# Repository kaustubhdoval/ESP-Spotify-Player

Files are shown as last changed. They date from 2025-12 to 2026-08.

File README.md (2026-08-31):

  <h1 align="center">ESP Spotify Player</h1>

  <p align="center">
    A Physical Spotify Remote, built around a custom ESP32-C3 PCB.
    <br />
    ·
    <a href="https://github.com/kaustubhdoval/ESP-Spotify-Player/issues">Report Bug</a>
    ·
    <a href="https://github.com/kaustubhdoval/ESP-Spotify-Player/issues">Request Feature</a>
    ·
  </p>

A Hardware Spotify Controller: buttons for play/pause/skip, a 128x64 OLED showing the current track and playback progress, and an on-device HTTPS server that handles the Spotify OAuth flow.

Ships as a from-scratch **KiCad PCB** (ESP32-C3) and also builds for a plain **ESP32 devkit** if you don't want to fab a board.

<p align="center">
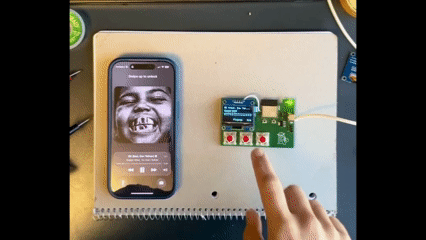
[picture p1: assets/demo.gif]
Demo of the Spotify player controlling playback
  
</p>
<p align="center">
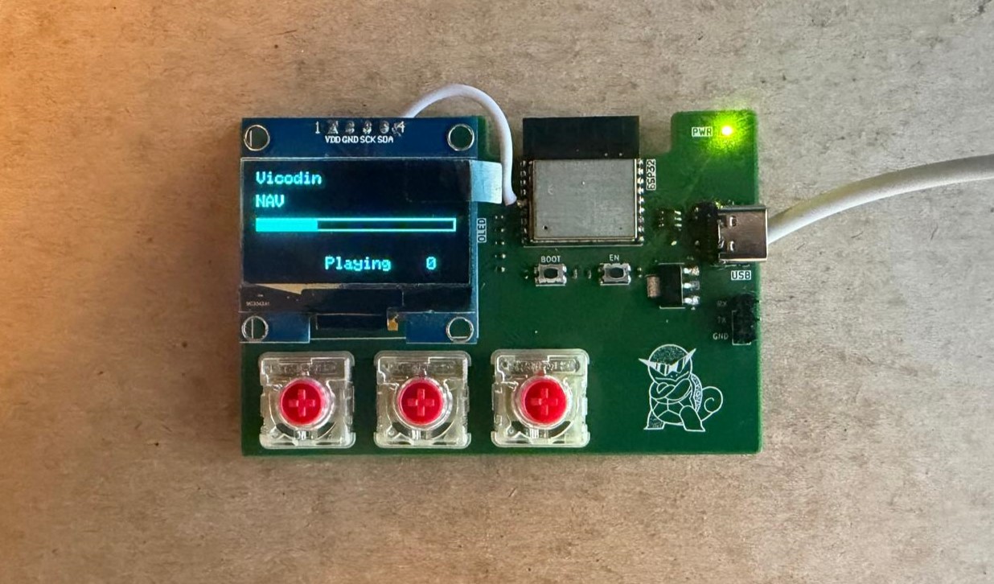
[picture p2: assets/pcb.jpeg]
Assembled custom PCB
  
</p>
<p align="center">
    Thanks to <a href="https://www.pcbway.com">PCBWay</a> for sponsoring fabrication!
  </p>

<br/>

## Features

- Play/pause, skip forward, skip back - instant, optimistic UI (screen updates before the Spotify API confirms)
- Live track name, artist, and playback-progress bar on a 128x64 SH1106 OLED
- Self-hosted OAuth: the ESP32 serves the Spotify login/callback pages itself over HTTPS, no server or app required
- Runs on a custom four-layer PCB (KiCad, ESP32-C3) **or** an off-the-shelf ESP32 devkit - see [Hardware](#hardware)

<br/>

## Repo Layout

```
src/    firmware (PlatformIO / Arduino framework)
pcb/    KiCad hardware design - schematic, PCB layout, fab/assembly outputs
lib/    vendored third-party library (patched for ESP32-C3 portability)
```

<br/>

## Hardware

This project supports two build targets. Pick whichever matches what you have.

| | Custom PCB | Generic ESP32 Devkit |
| --- | --- | --- |
| Board | ESP32-C3 (this repo's PCB) | Any classic ESP32 devkit |
| Rotary encoder (volume) | Not populated | Supported |
| PlatformIO environment  | `pcb` | `devkit` |
| Where to get it | Fab the board - see [View the PCB](#view-the-pcb) | Any ESP32 dev board you already own |

#### Wiring - Custom PCB (`env:pcb`)

| Component | Pin |
| --- | ----- |
| OLED SDA | GPIO6 |
| OLED SCL | GPIO7 |
| Previous button | GPIO5 |
| Play/Pause button | GPIO4 |
| Next button | GPIO3 |

No rotary encoder on this board - GPIO2 is a strapping pin on ESP32-C3, so it was dropped from the design.

#### Wiring - Generic Devkit (`env:devkit`)

| Component | Pin |
| --- | --- |
| OLED SDA | GPIO21 |
| OLED SCL | GPIO22 |
| Previous button | GPIO5  |
| Play/Pause button | GPIO18 |
| Next button | GPIO19 |
| Encoder CLK | GPIO4  |
| Encoder DT | GPIO2  |
| Encoder SW | GPIO15 |

> These pins are the environment defaults in `platformio.ini` - if your devkit's I2C or GPIOs are already used for something else, override them with `build_flags` in your environment rather than editing the source.

### View the PCB

The board is designed in KiCad. You can browse it interactively, no install required:

#### [**Open in KiCanvas »**](https://kicanvas.org/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)

Or open the files directly: [schematic](pcb/spotifyPlayerPcb.kicad_sch) · [PCB layout](pcb/spotifyPlayerPcb.kicad_pcb) · [assembly drawing](pcb/plots/spotifyPlayerPcb__Assembly.pdf) · [fab output](pcb/output/spotifyPlayerPcb.zip)

<br/>

## Setup

You need an **application registered on the Spotify Developer Dashboard** with the Web API enabled.

1. Rename [`src/secrets_EXAMPLE.h`](src/secrets_EXAMPLE.h) to `src/secrets.h`.
2. Fill in your WiFi credentials and Spotify `CLIENT_ID` / `CLIENT_SECRET` in `secrets.h`.
3. Build and flash for your hardware:

   ```sh
   pio run -e pcb -t upload      # custom PCB (ESP32-C3)
   # or
   pio run -e devkit -t upload   # generic ESP32 devkit
   ```

   > Custom PCB only: the board has no auto-reset circuit, just bare BOOT/RESET buttons. Hold **BOOT**, tap **RESET**, then release **BOOT** right as `pio run -t upload` starts trying to connect, or it'll fail with "Failed to connect to ESP32".

   If PlatformIO still can't find/upload to your board, flash the built binaries with `esptool` directly instead. Just build first (`pio run -e pcb`), then:

   ```sh
   esptool --chip esp32c3 --port COM3 write-flash ^
     0x0     .pio\build\pcb\bootloader.bin ^
     0x8000  .pio\build\pcb\partitions.bin ^
     0x10000 .pio\build\pcb\firmware.bin
   ```

   For a `devkit` build, swap `--chip esp32c3` for `--chip esp32` and `.pio\build\pcb\` for `.pio\build\devkit\`. Adjust `COM3` to your board's port. (This is the newer standalone `esptool` v5+ syntax; PlatformIO's bundled `esptool.py` uses `write_flash` with an underscore instead.)

4. Check the ESP's IP address on the OLED, or via the serial monitor:

   ```sh
   pio device monitor -e pcb      # or -e devkit
   ```

5. Add `https://<ESP_IP>/callback` as a Redirect URI on your Spotify app dashboard, and set the same value as `REDIRECT_URI` in `secrets.h`.
6. Re-flash with the updated `secrets.h`, then navigate to `https://<ESP_IP>` and log in with Spotify.

That's it - the device handles the OAuth exchange itself and starts controlling playback.

<br/>

## Dependencies

- adafruit/Adafruit GFX Library@^1.12.0
- adafruit/Adafruit SH110X@^2.1.12
- bblanchon/ArduinoJson@^7.4.1
- arduinogetstarted/ezButton@^1.0.6

Vendored locally in [lib/esp32_https_server](lib/esp32_https_server) (not pulled from the registry):

- fhessel/esp32_https_server@^1.0.0, patched to use `mbedtls_sha1` instead of the classic-ESP32-only `hwcrypto/sha.h`, so it builds on ESP32-C3 too.

<br/>

## Credits

- Thanks again to <a href="https://www.pcbway.com" target="_b;ank">PCBWay</a> for sponsoring fabrication.
  Their PCB manufacturing quality and service made it easy to bring the design from the schematic and layout to a finished, assembled board.
  <br/>
- Inspired by [MakeItForLess's Spotify Player](https://gitlab.com/makeitforless/spotify_controller)

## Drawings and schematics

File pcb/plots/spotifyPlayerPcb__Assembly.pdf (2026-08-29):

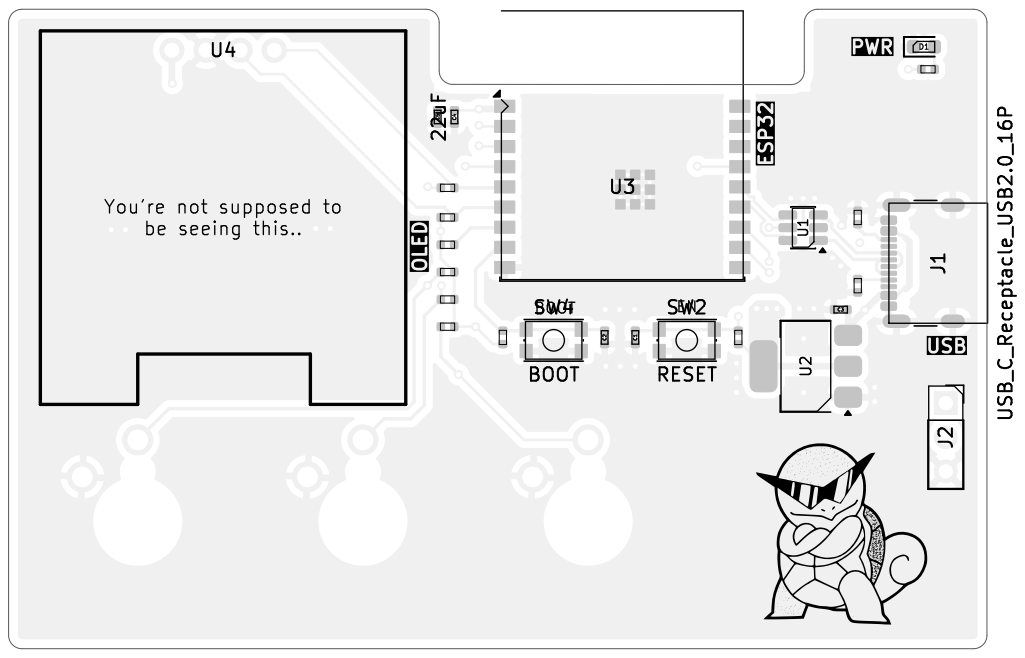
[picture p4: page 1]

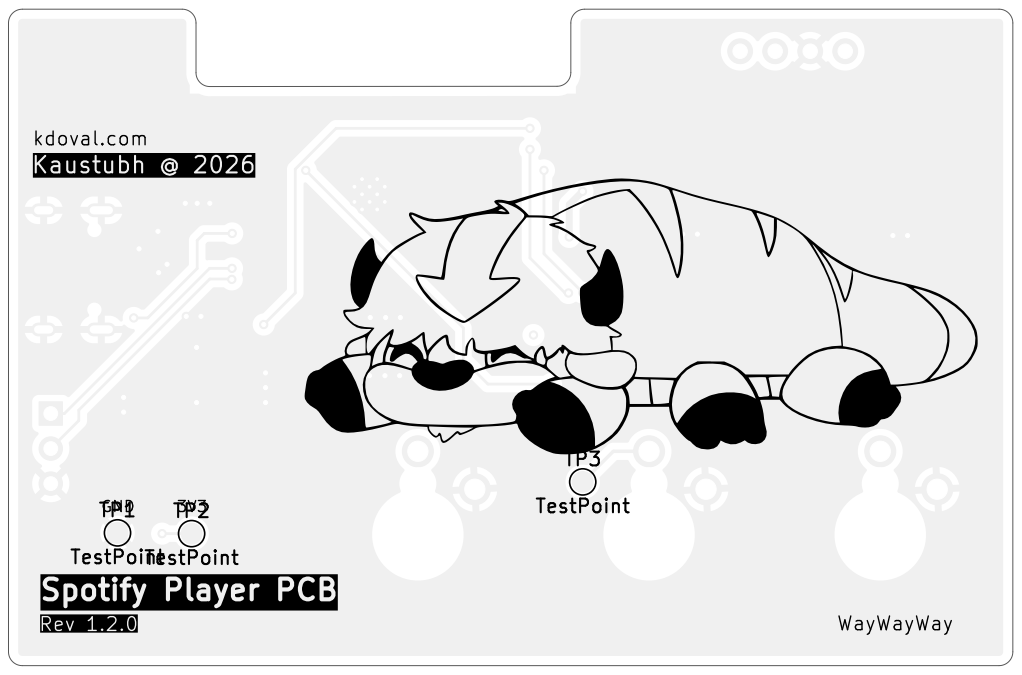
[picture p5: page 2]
GND; WayWayWay; kdoval.com; D Date: KiCad; E.D.A. 9.0.6 Size: A4; Rev:; Id: /1 Title: File: spotifyPlayerPcb.kicad_pcb Sheet: Black; And; White; BOT Board2Pdf:; Black; BOT -; Page 2/2

TestPoint TP3 TestPoint TP2 TestPoint TP1

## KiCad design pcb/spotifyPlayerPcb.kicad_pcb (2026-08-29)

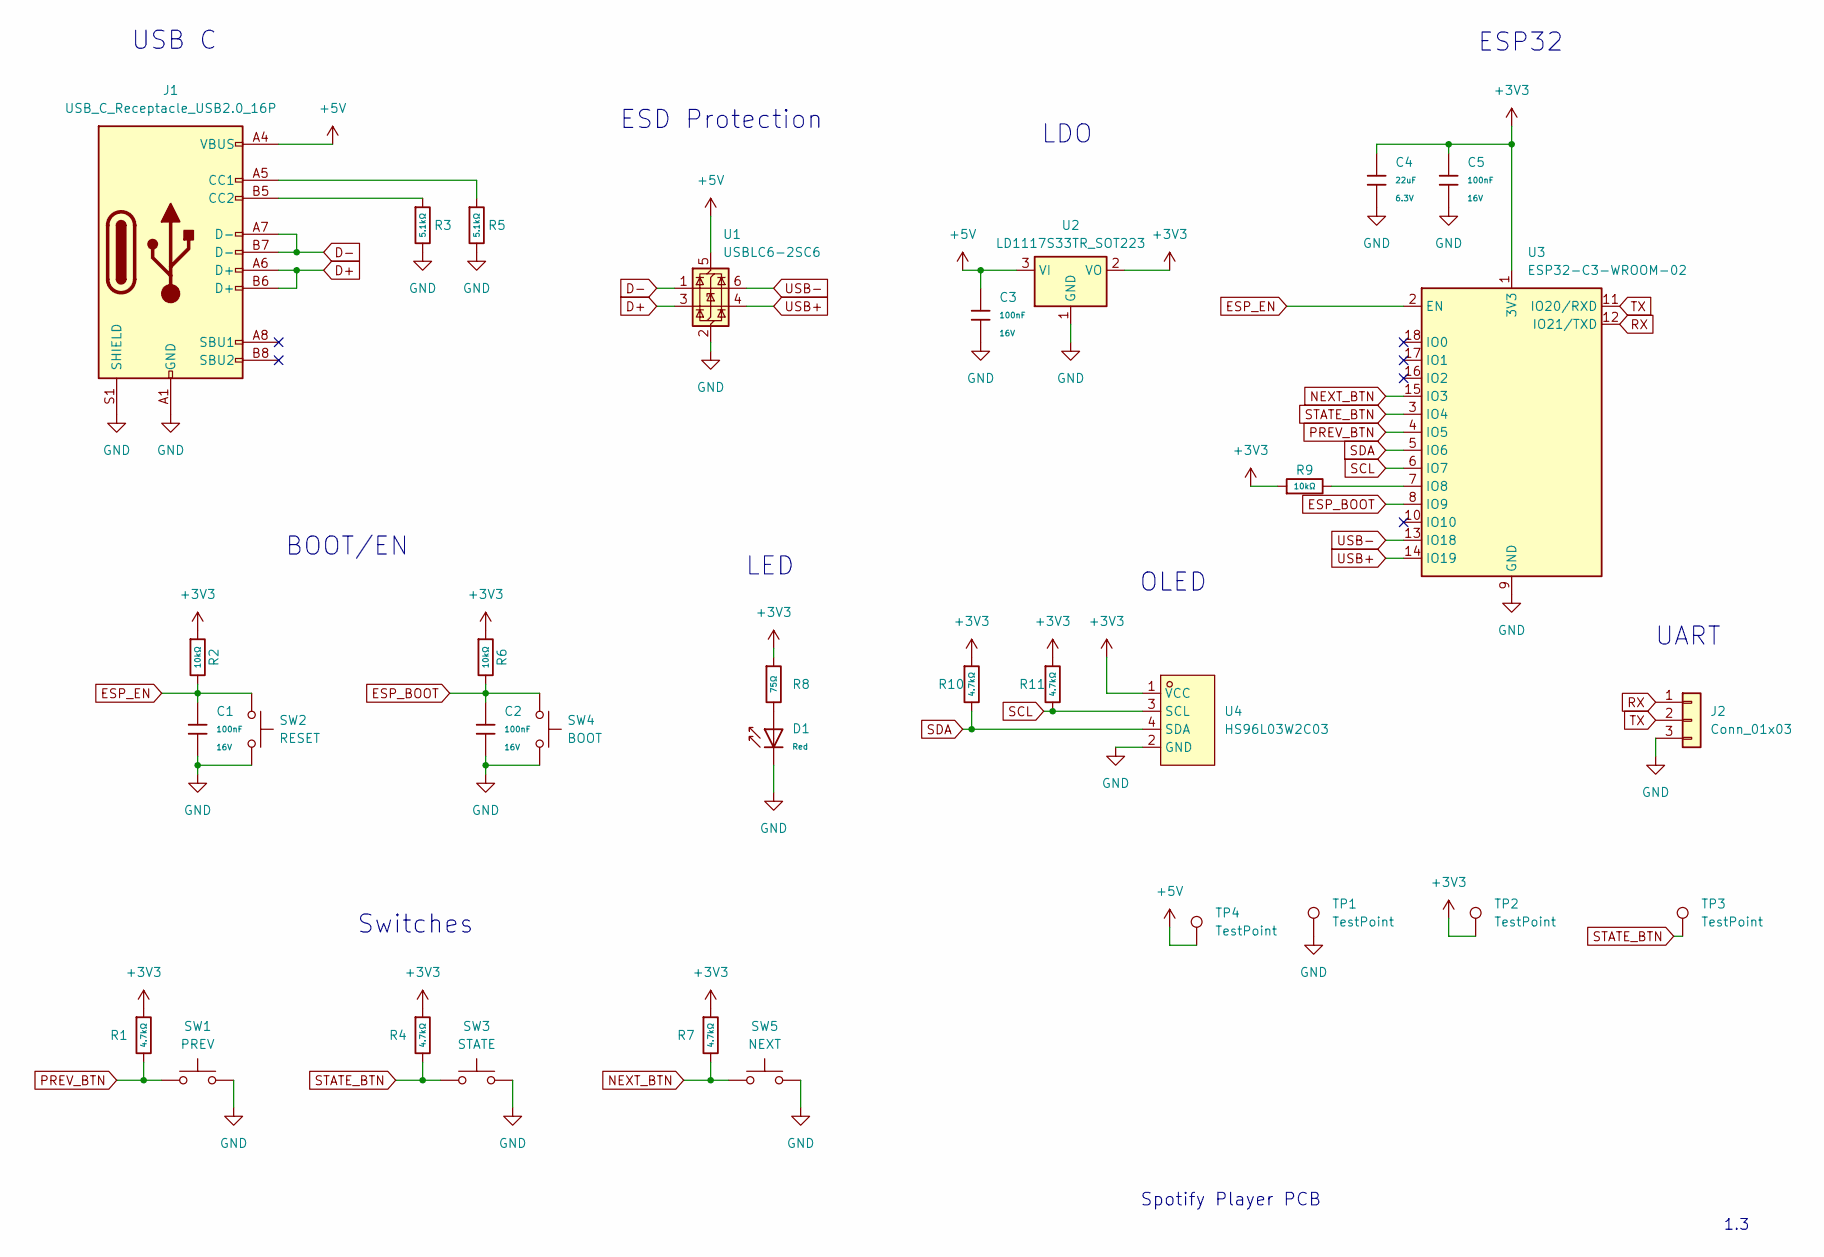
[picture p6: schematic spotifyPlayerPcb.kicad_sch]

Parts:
C1, C2, C3, C5: 100nF; C_0402; Voltage Rated 16V; Tolerance ±10%; Part CL05B104KO5NNNC; LCSC C1525
C4: 22uF; C_0402; Voltage Rated 6.3V; Tolerance ±20%; Part CL10A226MQ8NRNC; LCSC C59461
D1: Red; D_0603; Part KT-0603R; LCSC C2286
J1: USB_C_Receptacle_USB2.0_16P; USB_C_Receptacle_GCT_USB4105-xx-A_16P_TopMnt_Horizontal
J2: Conn_01x03; PinSocket_1x03_P2.54mm_Vertical
R1, R4, R7, R10, R11: 4.7kΩ; R_0402; Overload Voltage (Max) 50V; Tolerance ±1%; Part 0402WGF4701TCE; LCSC C25900
R2, R6, R9: 10kΩ; R_0402; Overload Voltage (Max) 50V; Tolerance ±1%; Part 0402WGF1002TCE; LCSC C25744
R3, R5: 5.1kΩ; R_0402; Overload Voltage (Max) 50V; Tolerance ±1%; Part 0402WGF5101TCE; LCSC C25905
R8: 75Ω; R_0402; Overload Voltage (Max) 50V; Tolerance ±1%; Part 0402WGF750JTCE; LCSC C25133
SW1: PREV; Cherry-MX-Low-Profile
SW2: RESET; SW_Push_1P1T_NO_CK_KMR2
SW3: STATE; Cherry-MX-Low-Profile
SW4: BOOT; SW_Push_1P1T_NO_CK_KMR2
SW5: NEXT; Cherry-MX-Low-Profile
TP1, TP2, TP3, TP4: TestPoint; TestPoint_Pad_D1.5mm
U1: USBLC6-2SC6; SOT-23-6
U2: LD1117S33TR_SOT223; SOT-223-3_TabPin2
U3: ESP32-C3-WROOM-02
U4: HS96L03W2C03; OLED-TH_L27.8-W27.2-P2.54_C9900033791; LCSC Part C5248080

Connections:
+3V3: C4.1, C5.1, R1.1, R2.1, R4.1, R6.1, R7.1, R8.1, R9.1, R10.1, R11.1, TP2.1, U2.2 (VO), U3.1 (3V3), U4.1 (VCC)
+5V: C3.1, J1.A4 (VBUS), J1.A9 (VBUS), J1.B4 (VBUS), J1.B9 (VBUS), TP4.1, U1.5 (VBUS), U2.3 (VI)
D+: J1.A6 (D+), J1.B6 (D+), U1.3 (I/O2)
D-: J1.A7 (D-), J1.B7 (D-), U1.1 (I/O1)
ESP_BOOT: C2.1, R6.2, SW4.1, U3.8 (IO9)
ESP_EN: C1.1, R2.2, SW2.1, U3.2 (EN)
GND: C1.2, C2.2, C3.2, C4.2, C5.2, D1.1, J1.A1 (GND), J1.A12 (GND), J1.B1 (GND), J1.B12 (GND), J1.S1 (SHIELD), J2.3, R3.2, R5.2, SW1.2, SW2.2, SW3.2, SW4.2, SW5.2, TP1.1, U1.2 (GND), U2.1 (GND), U3.9 (GND), U3.19 (GND), U4.2 (GND)
NEXT_BTN: R7.2, SW5.1, U3.15 (IO3)
unnamed: D1.2, R8.2
unnamed: J1.A5 (CC1), R5.1
unnamed: J1.B5 (CC2), R3.1
unnamed: R9.2, U3.7 (IO8)
PREV_BTN: R1.2, SW1.1, U3.4 (IO5)
RX: J2.1, U3.12 (IO21/TXD)
SCL: R11.2, U3.6 (IO7), U4.3 (SCL)
SDA: R10.2, U3.5 (IO6), U4.4 (SDA)
STATE_BTN: R4.2, SW3.1, TP3.1, U3.3 (IO4)
TX: J2.2, U3.11 (IO20/RXD)
USB+: U1.4 (I/O2), U3.14 (IO19)
USB-: U1.6 (I/O1), U3.13 (IO18)

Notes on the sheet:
Spotify Player PCB
UART
Switches
LED
LDO
BOOT/EN
ESD Protection
USB C
ESP32
OLED
1.3

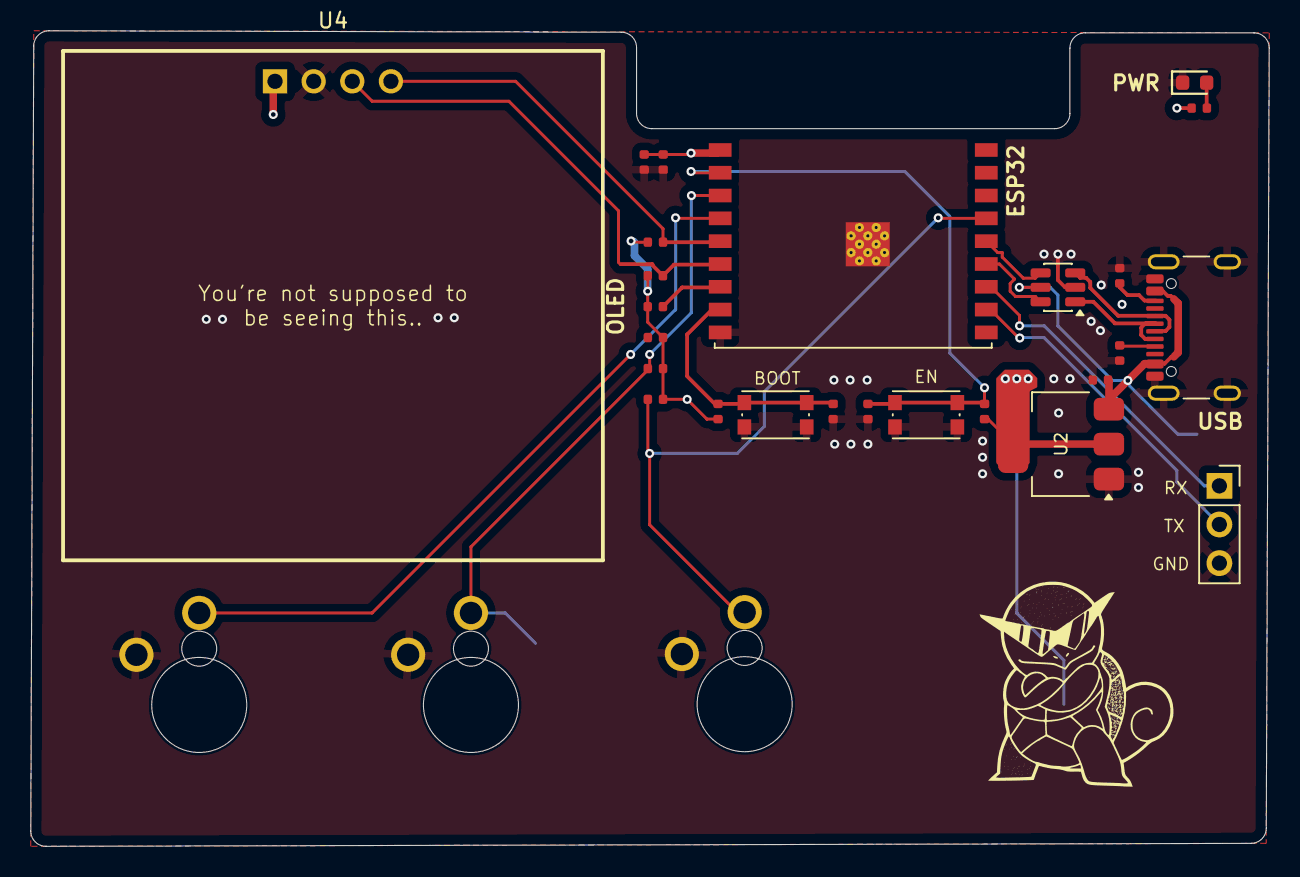
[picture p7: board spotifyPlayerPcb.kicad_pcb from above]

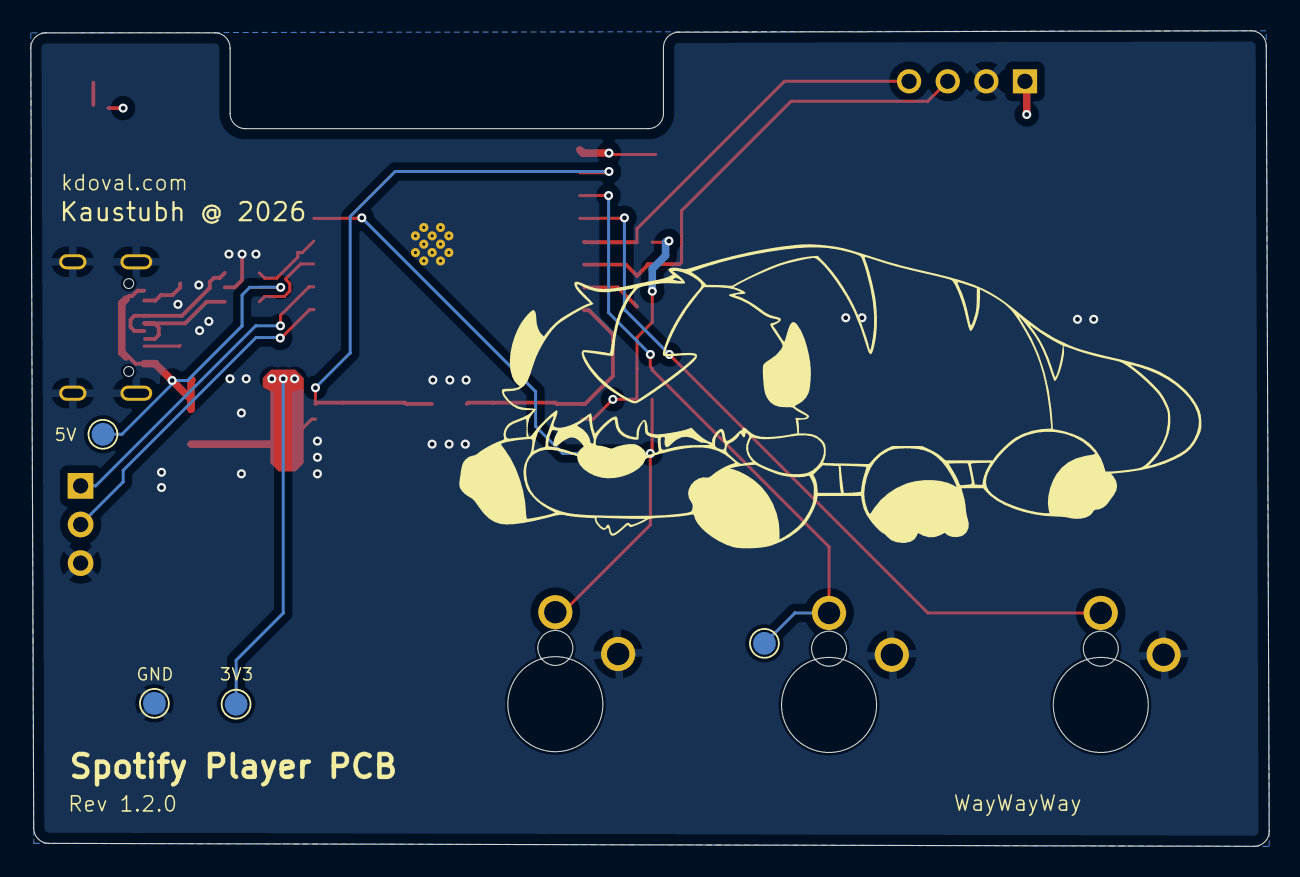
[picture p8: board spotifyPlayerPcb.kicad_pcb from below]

Board: 4 copper layers, 81.4 x 53.6 mm, 32 parts (4 on the bottom side), 20 nets.

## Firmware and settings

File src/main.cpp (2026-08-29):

/*ESP Spotify Player
- By Kaustubh
*/
#include <Wire.h>
#include <Adafruit_GFX.h>
#include <Adafruit_SH110X.h>
#include <ezButton.h>
#include <freertos/FreeRTOS.h>
#include <freertos/task.h>
#include <freertos/queue.h>
#include <driver/i2c.h> // i2c_set_timeout -- see the clamp in setup()
#ifdef ENABLE_ROTARY_ENCODER
#include "SoftHalfQuadEncoder.h"
#endif

#include "spotifyClient.h"

// Pin Definitions -- defaults are the custom PCB's wiring; the `devkit`
// PlatformIO environment overrides these via build_flags.
#ifndef PREV_BTN_PIN
#define PREV_BTN_PIN 5
#endif
#ifndef PLAY_BTN_PIN
#define PLAY_BTN_PIN 4
#endif
#ifndef NEXT_BTN_PIN
#define NEXT_BTN_PIN 3
#endif
#ifdef ENABLE_ROTARY_ENCODER
#ifndef ENC_CLK_PIN
#define ENC_CLK_PIN 4
#endif
#ifndef ENC_DT_PIN
#define ENC_DT_PIN 2
#endif
#ifndef ENC_SW_PIN
#define ENC_SW_PIN 15
#endif
#endif

// OLED Definitions
#define I2C_ADDRESS 0x3c
#define SCREEN_WIDTH 128
#define SCREEN_HEIGHT 64
#define OLED_RESET -1
// Defaults are the custom PCB's wiring (IO6/IO7, not this chip's default
// I2C pins IO8/IO9); the `devkit` environment overrides these too.
#ifndef OLED_SDA_PIN
#define OLED_SDA_PIN 6
#endif
#ifndef OLED_SCL_PIN
#define OLED_SCL_PIN 7
#endif

// Objects
Adafruit_SH1106G display = Adafruit_SH1106G(SCREEN_WIDTH, SCREEN_HEIGHT, &Wire, OLED_RESET, 400000, 400000);
#ifdef ENABLE_ROTARY_ENCODER
SoftHalfQuadEncoder encoder;
#endif

ezButton prevBtn(PREV_BTN_PIN);
ezButton playBtn(PLAY_BTN_PIN);
ezButton nextBtn(NEXT_BTN_PIN);
#ifdef ENABLE_ROTARY_ENCODER
ezButton encSwBtn(ENC_SW_PIN);
#endif

// Timing variables
unsigned long lastApiRefresh = 0;
unsigned long nextTrackRefresh = 0;

#define POST_ACTION_REFRESH_DELAY 400 // ms to let Spotify settle after an action

// Button events, produced by buttonTask (dedicated FreeRTOS task) and
// consumed by handleButtons() in the main loop. Polling + debouncing lives
// in its own task so presses are detected (and logged) immediately even
// while loop() is blocked on a Spotify HTTPS request.
enum ButtonEvent
{
  BTN_PREV,
  BTN_PLAY,
  BTN_NEXT
};
QueueHandle_t buttonQueue; // holds at most one pending, not-yet-started event

// Set the instant a press is accepted into the queue, cleared once
// handleButtons() finishes the resulting Spotify call
volatile bool actionInProgress = false;

void buttonTask(void *pvParameters)
{
  for (;;)
  {
    prevBtn.loop();
    playBtn.loop();
    nextBtn.loop();
#ifdef ENABLE_ROTARY_ENCODER
    encSwBtn.loop();
#endif

    ButtonEvent evt;
    bool pressed = false;
    const char *label = nullptr;

    if (prevBtn.isPressed())
    {
      evt = BTN_PREV;
      pressed = true;
      label = "Previous";
    }
    else if (playBtn.isPressed())
    {
      evt = BTN_PLAY;
      pressed = true;
      label = "Play/Pause";
    }
    else if (nextBtn.isPressed())
    {
      evt = BTN_NEXT;
      pressed = true;
      label = "Next";
    }

    if (pressed)
    {
      // Logged immediately, regardless of what loop() is currently doing
      Serial.printf("%s button pressed\n", label);

      if (actionInProgress)
      {
        Serial.println("  -> ignored, previous action still in progress");
      }
      else
      {
        actionInProgress = true;
        if (xQueueSend(buttonQueue, &evt, 0) != pdTRUE)
        {
          Serial.println("  -> queue full, dropping");
          actionInProgress = false;
        }
      }
    }

    vTaskDelay(pdMS_TO_TICKS(5));
  }
}

// False when the panel does not ACK at boot. Every display call is then
// skipped: (If display does not work, then skip trying to display to it)
bool displayPresent = false;

// Forward declarations
String truncateString(const String &input, int maxLength);
void handleButtons();
#ifdef ENABLE_ROTARY_ENCODER
void handleVolumeControl();
#endif
void drawScreen();

// Bitmap Definitions
static const unsigned char PROGMEM no_active_device[] = {0x07, 0xff, 0xff, 0xff, 0xff, 0xff, 0xff, 0xff, 0xff, 0xff, 0xf8, 0x00, 0x00, 0x00, 0x08, 0x00, 0x00, 0x00, 0x00, 0x00, 0x00, 0x00, 0x00, 0x00, 0x04, 0x00, 0x00, 0x00, 0x10, 0x00, 0x00, 0x00, 0x00, 0x00, 0x00, 0x00, 0x00, 0x00, 0x02, 0x00, 0x00, 0x00, 0x20, 0x00, 0x00, 0x00, 0x00, 0x00, 0x00, 0x00, 0x00, 0x00, 0x01, 0x00, 0x00, 0x00, 0x60, 0x00, 0x00, 0x00, 0x00, 0x00, 0x00, 0x00, 0x00, 0x00, 0x01, 0x00, 0x00, 0x00, 0xe0, 0x00, 0x00, 0x00, 0x00, 0x00, 0x00, 0x00, 0x00, 0x00, 0x01, 0xff, 0xff, 0xff, 0xe0, 0x00, 0x00, 0x00, 0x00, 0x00, 0x00, 0x00, 0x00, 0x00, 0x01, 0x00, 0x00, 0x01, 0xe0, 0x00, 0x00, 0x00, 0x00, 0x00, 0x00, 0x00, 0x00, 0x00, 0x01, 0x00, 0x00, 0x01, 0xe0, 0x07, 0xce, 0x78, 0x03, 0x80, 0x00, 0x41, 0x02, 0x00, 0x01, 0x00, 0x7c, 0x01, 0xe0, 0x04, 0x11, 0x44, 0x04, 0x40, 0x00, 0x40, 0x05, 0x00, 0x01, 0x00, 0x44, 0x01, 0xe0, 0x04, 0x10, 0x44, 0x04, 0x16, 0x39, 0xf3, 0x04, 0x44, 0x01, 0x00, 0x7c, 0x01, 0xe0, 0x07, 0x8e, 0x78, 0x03, 0x99, 0x44, 0x41, 0x0e, 0x44, 0x01, 0x00, 0x7c, 0x01, 0xe0, 0x04, 0x01, 0x40, 0x00, 0x59, 0x44, 0x41, 0x04, 0x3c, 0x01, 0x00, 0x7c, 0x01, 0xe0, 0x04, 0x11, 0x40, 0x04, 0x56, 0x44, 0x51, 0x04, 0x04, 0x01, 0x00, 0x00, 0x01, 0xe0, 0x07, 0xce, 0x40, 0x03, 0x90, 0x38, 0x23, 0x84, 0x44, 0x01, 0x00, 0x00, 0x01, 0xe0, 0x00, 0x00, 0x00, 0x00, 0x10, 0x00, 0x00, 0x00, 0x38, 0x01, 0x1f, 0xff, 0x9f, 0xe0, 0x00, 0x00, 0x00, 0x00, 0x00, 0x00, 0x00, 0x00, 0x00, 0x01, 0x10, 0x00, 0x91, 0xe0, 0x00, 0x00, 0x00, 0x00, 0x00, 0x00, 0x00, 0x00, 0x00, 0x01, 0xf0, 0x00, 0xf1, 0xe0, 0x00, 0x00, 0x00, 0x00, 0x00, 0x00, 0x00, 0x00, 0x00, 0x01, 0x00, 0x00, 0x01, 0xe0, 0x00, 0x00, 0x0f, 0x18, 0x00, 0x00, 0x00, 0x00, 0x00, 0x01, 0x00, 0x7c, 0x01, 0xe0, 0x00, 0x00, 0x08, 0x88, 0x00, 0x00, 0x00, 0x00, 0x00, 0x01, 0x00, 0x7c, 0x01, 0xe0, 0x00, 0x00, 0x08, 0x88, 0x62, 0x27, 0x2c, 0x00, 0x00, 0x01, 0x00, 0x7c, 0x01, 0xe0, 0x00, 0x00, 0x0f, 0x08, 0x12, 0x28, 0xb2, 0x00, 0x00, 0x01, 0x00, 0x44, 0x01, 0xe0, 0x00, 0x00, 0x08, 0x08, 0x71, 0xef, 0xa0, 0x00, 0x00, 0x01, 0x00, 0x7c, 0x01, 0xe0, 0x00, 0x00, 0x08, 0x08, 0x90, 0x28, 0x20, 0x00, 0x00, 0x01, 0x00, 0x00, 0x01, 0xe0, 0x00, 0x00, 0x08, 0x1c, 0x7a, 0x27, 0x20, 0x00, 0x00, 0x01, 0x00, 0x00, 0x01, 0xe0, 0x00, 0x00, 0x00, 0x00, 0x01, 0xc0, 0x00, 0x00, 0x00, 0x01, 0xff, 0xff, 0xff, 0xe0, 0x00, 0x00, 0x00, 0x00, 0x00, 0x00, 0x00, 0x00, 0x00, 0x01, 0xff, 0xff, 0xfe, 0xe0, 0x00, 0x00, 0x00, 0x00, 0x00, 0x00, 0x00, 0x00, 0x00, 0x01, 0xff, 0xff, 0xfc, 0xe0, 0x00, 0x00, 0x00, 0x00, 0x00, 0x00, 0x00, 0x00, 0x00, 0x01, 0x00, 0x00, 0x00, 0xf0, 0x00, 0x00, 0x00, 0x00, 0x00, 0x00, 0x00, 0x00, 0x00, 0x02, 0x00, 0x00, 0x00, 0xf8, 0x00, 0x00, 0x00, 0x00, 0x00, 0x00, 0x00, 0x00, 0x00, 0x04, 0x00, 0x00, 0x00, 0x7f, 0xff, 0xff, 0xff, 0xff, 0xff, 0xff, 0xff, 0xff, 0xff, 0xf8, 0x00, 0x00, 0x00, 0x3f, 0xff, 0xff, 0xff, 0xff, 0xff, 0xff, 0xff, 0xff, 0xff, 0xf0, 0x00, 0x00, 0x00, 0x1f, 0xff, 0xff, 0xff, 0xff, 0xff, 0xff, 0xff, 0xff, 0xff, 0xe0, 0x00, 0x00, 0x00, 0x00, 0x00, 0x00, 0x00, 0x00, 0x00, 0x00, 0x00, 0x00, 0x00, 0x00, 0x00, 0x00, 0x00, 0x00, 0x00, 0x00, 0x00, 0x00, 0x00, 0x00, 0x00, 0x00, 0x00, 0x00, 0x00, 0x00, 0x00, 0x00, 0x00, 0x00, 0x00, 0x00, 0x00, 0x00, 0x00, 0x00, 0x00, 0x00, 0x00, 0x00, 0x00, 0x00, 0x00, 0x00, 0x00, 0x00, 0x00, 0x00, 0x00, 0x00, 0x00, 0x00, 0x00, 0x00, 0x00, 0x00, 0x00, 0x00, 0x00, 0x00, 0x00, 0x00, 0x00, 0x00, 0x00, 0x00, 0x00, 0x00, 0x00, 0x00, 0x00, 0x00, 0x00, 0x00, 0x00, 0x00, 0x00, 0x00, 0x00, 0x00, 0x00, 0x00, 0x00, 0x00, 0x00, 0x00, 0x00, 0x00, 0x00, 0x00, 0x00, 0x00, 0x00, 0x00, 0x00, 0x00, 0x00, 0x02, 0x20, 0x00, 0x20, 0x02, 0x08, 0x00, 0x00, 0x3c, 0x00, 0x02, 0x00, 0x00, 0x00, 0x02, 0x20, 0x00, 0x50, 0x02, 0x00, 0x00, 0x00, 0x22, 0x00, 0x00, 0x00, 0x00, 0x00, 0x03, 0x27, 0x00, 0x89, 0xcf, 0x98, 0x89, 0xc0, 0x22, 0x72, 0x26, 0x1c, 0x70, 0x00, 0x02, 0xa8, 0x80, 0x8a, 0x22, 0x08, 0x8a, 0x20, 0x22, 0x8a, 0x22, 0x22, 0x88, 0x00, 0x02, 0x68, 0x80, 0xfa, 0x02, 0x08, 0x8b, 0xe0, 0x22, 0xfa, 0x22, 0x20, 0xf8, 0x00, 0x02, 0x28, 0x80, 0x8a, 0x22, 0x88, 0x52, 0x00, 0x22, 0x81, 0x42, 0x22, 0x80, 0x00, 0x02, 0x27, 0x00, 0x89, 0xc1, 0x1c, 0x21, 0xc0, 0x3c, 0x70, 0x87, 0x1c, 0x70, 0x00};
static const unsigned char PROGMEM splash_screen[] = {0x07, 0xff, 0xff, 0xff, 0xff, 0xff, 0xff, 0xff, 0xff, 0xff, 0xf8, 0x00, 0x00, 0x00, 0x08, 0x00, 0x00, 0x00, 0x00, 0x00, 0x00, 0x00, 0x00, 0x00, 0x04, 0x00, 0x00, 0x00, 0x10, 0x00, 0x00, 0x00, 0x00, 0x00, 0x00, 0x00, 0x00, 0x00, 0x02, 0x00, 0x00, 0x00, 0x20, 0x00, 0x00, 0x00, 0x00, 0x00, 0x00, 0x00, 0x00, 0x00, 0x01, 0x00, 0x00, 0x00, 0x60, 0x00, 0x00, 0x00, 0x00, 0x00, 0x00, 0x00, 0x00, 0x00, 0x01, 0x00, 0x00, 0x00, 0xe0, 0x00, 0x00, 0x00, 0x00, 0x00, 0x00, 0x00, 0x00, 0x00, 0x01, 0xff, 0xff, 0xff, 0xe0, 0x00, 0x00, 0x00, 0x00, 0x00, 0x00, 0x00, 0x00, 0x00, 0x01, 0x00, 0x00, 0x01, 0xe0, 0x00, 0x00, 0x00, 0x00, 0x00, 0x00, 0x00, 0x00, 0x00, 0x01, 0x00, 0x00, 0x01, 0xe0, 0x07, 0xce, 0x78, 0x03, 0x80, 0x00, 0x41, 0x02, 0x00, 0x01, 0x00, 0x7c, 0x01, 0xe0, 0x04, 0x11, 0x44, 0x04, 0x40, 0x00, 0x40, 0x05, 0x00, 0x01, 0x00, 0x44, 0x01, 0xe0, 0x04, 0x10, 0x44, 0x04, 0x16, 0x39, 0xf3, 0x04, 0x44, 0x01, 0x00, 0x7c, 0x01, 0xe0, 0x07, 0x8e, 0x78, 0x03, 0x99, 0x44, 0x41, 0x0e, 0x44, 0x01, 0x00, 0x7c, 0x01, 0xe0, 0x04, 0x01, 0x40, 0x00, 0x59, 0x44, 0x41, 0x04, 0x3c, 0x01, 0x00, 0x7c, 0x01, 0xe0, 0x04, 0x11, 0x40, 0x04, 0x56, 0x44, 0x51, 0x04, 0x04, 0x01, 0x00, 0x00, 0x01, 0xe0, 0x07, 0xce, 0x40, 0x03, 0x90, 0x38, 0x23, 0x84, 0x44, 0x01, 0x00, 0x00, 0x01, 0xe0, 0x00, 0x00, 0x00, 0x00, 0x10, 0x00, 0x00, 0x00, 0x38, 0x01, 0x1f, 0xff, 0x9f, 0xe0, 0x00, 0x00, 0x00, 0x00, 0x00, 0x00, 0x00, 0x00, 0x00, 0x01, 0x10, 0x00, 0x91, 0xe0, 0x00, 0x00, 0x00, 0x00, 0x00, 0x00, 0x00, 0x00, 0x00, 0x01, 0xf0, 0x00, 0xf1, 0xe0, 0x00, 0x00, 0x00, 0x00, 0x00, 0x00, 0x00, 0x00, 0x00, 0x01, 0x00, 0x00, 0x01, 0xe0, 0x00, 0x00, 0x0f, 0x18, 0x00, 0x00, 0x00, 0x00, 0x00, 0x01, 0x00, 0x7c, 0x01, 0xe0, 0x00, 0x00, 0x08, 0x88, 0x00, 0x00, 0x00, 0x00, 0x00, 0x01, 0x00, 0x7c, 0x01, 0xe0, 0x00, 0x00, 0x08, 0x88, 0x62, 0x27, 0x2c, 0x00, 0x00, 0x01, 0x00, 0x7c, 0x01, 0xe0, 0x00, 0x00, 0x0f, 0x08, 0x12, 0x28, 0xb2, 0x00, 0x00, 0x01, 0x00, 0x44, 0x01, 0xe0, 0x00, 0x00, 0x08, 0x08, 0x71, 0xef, 0xa0, 0x00, 0x00, 0x01, 0x00, 0x7c, 0x01, 0xe0, 0x00, 0x00, 0x08, 0x08, 0x90, 0x28, 0x20, 0x00, 0x00, 0x01, 0x00, 0x00, 0x01, 0xe0, 0x00, 0x00, 0x08, 0x1c, 0x7a, 0x27, 0x20, 0x00, 0x00, 0x01, 0x00, 0x00, 0x01, 0xe0, 0x00, 0x00, 0x00, 0x00, 0x01, 0xc0, 0x00, 0x00, 0x00, 0x01, 0xff, 0xff, 0xff, 0xe0, 0x00, 0x00, 0x00, 0x00, 0x00, 0x00, 0x00, 0x00, 0x00, 0x01, 0xff, 0xff, 0xfe, 0xe0, 0x00, 0x00, 0x00, 0x00, 0x00, 0x00, 0x00, 0x00, 0x00, 0x01, 0xff, 0xff, 0xfc, 0xe0, 0x00, 0x00, 0x00, 0x00, 0x00, 0x00, 0x00, 0x00, 0x00, 0x01, 0x00, 0x00, 0x00, 0xf0, 0x00, 0x00, 0x00, 0x00, 0x00, 0x00, 0x00, 0x00, 0x00, 0x02, 0x00, 0x00, 0x00, 0xf8, 0x00, 0x00, 0x00, 0x00, 0x00, 0x00, 0x00, 0x00, 0x00, 0x04, 0x00, 0x00, 0x00, 0x7f, 0xff, 0xff, 0xff, 0xff, 0xff, 0xff, 0xff, 0xff, 0xff, 0xf8, 0x00, 0x00, 0x00, 0x3f, 0xff, 0xff, 0xff, 0xff, 0xff, 0xff, 0xff, 0xff, 0xff, 0xf0, 0x00, 0x00, 0x00, 0x1f, 0xff, 0xff, 0xff, 0xff, 0xff, 0xff, 0xff, 0xff, 0xff, 0xe0, 0x00, 0x00, 0x00, 0x00, 0x00, 0x00, 0x00, 0x00, 0x00, 0x00, 0x00, 0x00, 0x00, 0x00, 0x00, 0x00, 0x00, 0x00, 0x00, 0x00, 0x00, 0x00, 0x00, 0x00, 0x00, 0x00, 0x00, 0x00, 0x00, 0x00, 0x00, 0x00, 0x00, 0x00, 0x00, 0x00, 0x00, 0x00, 0x00, 0x00, 0x00, 0x00, 0x00, 0x00, 0x00, 0x00, 0x00, 0x00, 0x00, 0x00, 0x00, 0x00, 0x00, 0x00, 0x00, 0x00, 0x00, 0x00, 0x00, 0x00, 0x00, 0x00, 0x00, 0x00, 0x00, 0x00, 0x00, 0x00, 0x00, 0x00, 0x00, 0x00, 0x00, 0x00, 0x00, 0x00, 0x00, 0x00, 0x00, 0x00, 0x00, 0x00, 0x00, 0x00, 0x00, 0x00, 0x00, 0x00, 0x00, 0x00, 0x00, 0x00, 0x00, 0x00, 0x00, 0x00, 0x00, 0x00, 0x00, 0x00, 0x00, 0x00, 0x00, 0x00, 0x00, 0x00, 0x00, 0x00, 0x00, 0x00, 0x00, 0x00, 0x00, 0x00, 0x00, 0x00, 0x00, 0x0f, 0x00, 0x02, 0x20, 0x00, 0x00, 0x80, 0x20, 0x80, 0x00, 0x00, 0x00, 0x00, 0x00, 0x08, 0x80, 0x02, 0x40, 0x00, 0x00, 0x80, 0x20, 0x80, 0x00, 0x00, 0x00, 0x00, 0x00, 0x08, 0xa2, 0x02, 0x86, 0x22, 0x7b, 0xe8, 0xac, 0xb0, 0x00, 0x00, 0x00, 0x00, 0x00, 0x0f, 0x22, 0x03, 0x01, 0x22, 0x80, 0x88, 0xb2, 0xc8, 0x00, 0x00, 0x00, 0x00, 0x00, 0x08, 0x9e, 0x02, 0x87, 0x22, 0x70, 0x88, 0xa2, 0x88, 0x00, 0x00, 0x00, 0x00, 0x00, 0x08, 0x82, 0x02, 0x49, 0x26, 0x08, 0xa9, 0xb2, 0x88, 0x00, 0x00, 0x00, 0x00, 0x00, 0x0f, 0x22, 0x02, 0x27, 0x9a, 0xf0, 0x46, 0xac, 0x88, 0x00, 0x00, 0x00, 0x00, 0x00, 0x00, 0x1c, 0x00, 0x00, 0x00, 0x00, 0x00, 0x00, 0x00, 0x00, 0x00, 0x00};
static const unsigned char PROGMEM configuring[] = {0x80, 0xe0, 0x00, 0x00, 0x00, 0x00, 0x00, 0x00, 0x00, 0x00, 0x00, 0x00, 0x00, 0xc1, 0x60, 0x00, 0x00, 0x00, 0x00, 0x00, 0x00, 0x00, 0x00, 0x00, 0x00, 0x00, 0x42, 0x80, 0x00, 0x00, 0x00, 0x00, 0x00, 0x00, 0x00, 0x00, 0x00, 0x00, 0x00, 0x22, 0x8c, 0x00, 0x00, 0x00, 0x00, 0x00, 0x00, 0x00, 0x00, 0x00, 0x00, 0x00, 0x13, 0x0c, 0x07, 0x00, 0x00, 0x42, 0x00, 0x00, 0x02, 0x00, 0x00, 0x00, 0x00, 0x0a, 0xb4, 0x08, 0x80, 0x00, 0xa0, 0x00, 0x00, 0x00, 0x00, 0x00, 0x00, 0x00, 0x06, 0x48, 0x08, 0x1c, 0xb0, 0x86, 0x1c, 0x8a, 0xc6, 0x2c, 0x70, 0x00, 0x00, 0x05, 0xf0, 0x08, 0x22, 0xc9, 0xc2, 0x26, 0x8b, 0x22, 0x32, 0x98, 0x00, 0x00, 0x0b, 0x00, 0x08, 0x22, 0x88, 0x82, 0x26, 0x8a, 0x02, 0x22, 0x98, 0x00, 0x00, 0x14, 0xe0, 0x08, 0xa2, 0x88, 0x82, 0x1a, 0x9a, 0x02, 0x22, 0x68, 0xc3, 0x0c, 0x29, 0xb0, 0x07, 0x1c, 0x88, 0x87, 0x02, 0x6a, 0x07, 0x22, 0x08, 0xc3, 0x0c, 0x50, 0xd8, 0x00, 0x00, 0x00, 0x00, 0x1c, 0x00, 0x00, 0x00, 0x70, 0x00, 0x00, 0xa0, 0x6c, 0x00, 0x00, 0x00, 0x00, 0x00, 0x00, 0x00, 0x00, 0x00, 0x00, 0x00, 0xc0, 0x34, 0x00, 0x00, 0x00, 0x00, 0x00, 0x00, 0x00, 0x00, 0x00, 0x00, 0x00, 0x00, 0x1c, 0x00, 0x00, 0x00, 0x00, 0x00, 0x00, 0x00, 0x00, 0x00, 0x00, 0x00};

void drawScreen()
{
  if (!displayPresent)
  {
    return; // headless: skip the ~1s-per-write I2C stall entirely
  }

  display.clearDisplay();

  if (!spotifyConnection.getActiveStatus())
  {
    // Show the no active device screen
    display.drawBitmap(9, 8, no_active_device, 112, 49, 1);
  }
  else
  {
    // Display content for active device
    display.setTextColor(SH110X_WHITE);
    display.setTextSize(1);

    // Truncate long strings
    String songName = truncateString(spotifyConnection.getCurrentSong().song, 20);
    String artistName = truncateString(spotifyConnection.getCurrentSong().artist, 20);

    // Display song info
    display.setCursor(0, 0);
    display.print(songName);

    display.setCursor(0, 15);
    display.print(artistName);

    // Draw progress bar
    int barY = 30;
    int barHeight = 8;
    // map() logs an error and misbehaves when durationMs is 0, which happens
    // whenever the player reports a device but no track.
    int durationMs = spotifyConnection.getCurrentSong().durationMs;
    int barWidth = (durationMs > 0)
                       ? map(spotifyConnection.getCurrentPositionMs(), 0, durationMs, 0, SCREEN_WIDTH)
                       : 0;

    display.drawRect(0, barY, SCREEN_WIDTH, barHeight, SH110X_WHITE);
    display.fillRect(0, barY, barWidth, barHeight, SH110X_WHITE);

    // Display play/pause state
    display.setCursor(45, 55);
    display.print(spotifyConnection.getStatus() ? "Playing" : "Paused");

    // Display volume
    display.setCursor(110, 55);
    display.print(spotifyConnection.volCtrl ? String(spotifyConnection.currVol) : "N/A");
  }

  display.display();
}

// Helper function to truncate strings
String truncateString(const String &input, int maxLength)
{
  if (input.length() <= maxLength)
    return input;
  return input.substring(0, maxLength - 3) + "...";
}

// Button handler function - drains events produced by buttonTask.
// buttonTask already logs the press and refuses to enqueue a new one while
// actionInProgress is set, so every event reaching here is meant to run now.
void handleButtons()
{
  ButtonEvent evt;
  if (xQueueReceive(buttonQueue, &evt, 0) != pdTRUE)
  {
    return;
  }

  switch (evt)
  {
  case BTN_PREV:
    spotifyConnection.skipBack();
    // The track changed but we don't know to what yet -- reset the progress
    // bar so the screen reacts now, and let the deferred refresh fill in the
    // new title/artist.
    spotifyConnection.currentSongPositionMs = 0;
    drawScreen();
    break;
  case BTN_PLAY:
    // togglePlay() already draws the new play/pause state optimistically.
    spotifyConnection.togglePlay();
    break;
  case BTN_NEXT:
    spotifyConnection.skipForward();
    spotifyConnection.currentSongPositionMs = 0;
    drawScreen();
    break;
  }

  // Schedule the confirming fetch instead of blocking the press on it. This
  // halves the round trips a press has to wait for.
  nextTrackRefresh = millis() + POST_ACTION_REFRESH_DELAY;
  if (nextTrackRefresh == 0)
  {
    nextTrackRefresh = 1; // 0 is the "nothing scheduled" sentinel
  }

  actionInProgress = false;
}
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
void loop()
{
  unsigned long currentMillis = millis();

  // If not authenticated, handle web server requests
  if (!spotifyConnection.accessTokenSet)
  {
    secureServer->loop();
    return;
  }

  // Close server after authentication
  if (serverOn)
  {
    secureServer->stop();
    serverOn = false;
  }

  // Refresh access token if needed. Backed off on failure
  static unsigned long refreshRetryAfter = 0;
  if ((currentMillis - spotifyConnection.tokenStartTime) / 1000 > spotifyConnection.tokenExpireTime - 60 &&
      (refreshRetryAfter == 0 || (long)(currentMillis - refreshRetryAfter) >= 0))
  {
    Serial.println("Refreshing token");
    if (spotifyConnection.refreshAuth())
    {
      Serial.println("Token refreshed successfully");
      refreshRetryAfter = 0;
    }
    else
    {
      Serial.println("Token refresh failed, retrying in 10s");
      refreshRetryAfter = millis() + 10000;
    }
  }

  // Handle user inputs
  handleButtons();
#ifdef ENABLE_ROTARY_ENCODER
  handleVolumeControl();
#endif

  // Update track info periodically, or sooner if a button press scheduled a
  // confirming fetch.
  unsigned long pollInterval = spotifyConnection.isPlaying ? API_REFRESH_INTERVAL : 30000; // 30s when paused
  bool refreshDue = (currentMillis - lastApiRefresh > pollInterval);

  if (nextTrackRefresh != 0 && (long)(currentMillis - nextTrackRefresh) >= 0)
  {
    refreshDue = true;
    nextTrackRefresh = 0;
  }

  if (refreshDue)
  {
    spotifyConnection.getTrackInfo();
    lastApiRefresh = currentMillis;
    return; // re-enter loop() so a press queued during the fetch runs next
  }

  // Nothing pending: spend the idle time paying off any TLS handshake that
  // would otherwise be charged to the next button press.
  if (!actionInProgress && nextTrackRefresh == 0)
  {
    spotifyConnection.maintainConnection("api.spotify.com");
  }
}

// Web server handlers
void handleRoot(HTTPRequest *req, HTTPResponse *res)
{
  Serial.println("Handling root request");

  // Static buffer (safer than stack allocation)
  static char page[8192];

  // Generate the page
  if (snprintf(page, sizeof(page), mainPage, CLIENT_ID, REDIRECT_URI) < 0)
  {
    res->setStatusCode(500);
    res->setStatusText("Internal Server Error");
    res->println("Failed to generate page");
    return;
  }

  // Set headers and send response
  res->setHeader("Content-Type", "text/html");
  res->println(page);
}

void handleCallbackPage(HTTPRequest *req, HTTPResponse *res)
{
  // Debug logging
  Serial.println("=== CALLBACK HEADERS ===");
  Serial.print("Request line: ");
  Serial.println(req->getRequestString().c_str());

  // Get the "code" parameter from query string
  std::string code;
  bool hasCode = req->getParams()->getQueryParameter("code", code);

  if (!spotifyConnection.accessTokenSet)
  {
    if (code.empty())
    {
      static char page[8192];
      if (snprintf(page, sizeof(page), errorPage, CLIENT_ID, REDIRECT_URI) < 0)
      {
        res->setStatusCode(500);
        res->setStatusText("Internal Server Error");
        res->println("Error page generation failed");
        return;
      }
      res->setHeader("Content-Type", "text/html");
      res->println(page);
    }
    else
    {
      String codeStr = String(code.c_str());
      if (spotifyConnection.getUserCode(codeStr))
      {
        res->setHeader("Content-Type", "text/plain");
        res->print("Spotify setup complete. Refresh in: ");
        res->print(String(spotifyConnection.tokenExpireTime));
      }
      else
      {
        static char page[800];
        if (snprintf(page, sizeof(page), errorPage, CLIENT_ID, REDIRECT_URI) < 0)
        {
          res->setStatusCode(500);
          res->setStatusText("Internal Server Error");
          res->println("Error page generation failed");
          return;
        }
        res->setHeader("Content-Type", "text/html");
        res->println(page);
      }
    }
  }
  else
  {
    res->setHeader("Content-Type", "text/plain");
    res->println("Already authenticated");
  }
}

void handle404(HTTPRequest *req, HTTPResponse *res)
{
  // Discard request body if any
  req->discardRequestBody();

  // Set response status
  res->setStatusCode(404);
  res->setStatusText("Not Found");

  // Set content type
  res->setHeader("Content-Type", "text/html");

  // Write 404 page
  res->println("<!DOCTYPE html>");
  res->println("<html>");
  res->println("<head><title>Not Found</title></head>");
  res->println("<body><h1>404 Not Found</h1><p>The requested resource was not found on this server.</p></body>");
  res->println("</html>");
}

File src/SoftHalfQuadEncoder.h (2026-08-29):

#ifndef SOFT_HALF_QUAD_ENCODER_H
#define SOFT_HALF_QUAD_ENCODER_H

#include <Arduino.h>

// ESP32-C3 has no PCNT peripheral (SOC_PCNT_SUPPORTED is unset), so the
// ESP32Encoder library cannot be used on the PCB. This reproduces its
// "half quad" decoding in software: both edges of pin A are counted, and
// the level of pin B at the time of the edge gives the direction.
class SoftHalfQuadEncoder
{
public:
  void attachHalfQuad(int aPin, int bPin)
  {
    instance = this;
    _aPin = aPin;
    _bPin = bPin;
    pinMode(aPin, INPUT_PULLUP);
    pinMode(bPin, INPUT_PULLUP);
    attachInterrupt(digitalPinToInterrupt(aPin), isr, CHANGE);
  }

  int64_t getCount()
  {
    portENTER_CRITICAL(&_mux);
    int64_t result = _count;
    portEXIT_CRITICAL(&_mux);
    return result;
  }

  void setCount(int64_t value)
  {
    portENTER_CRITICAL(&_mux);
    _count = value;
    portEXIT_CRITICAL(&_mux);
  }

private:
  static void IRAM_ATTR isr()
  {
    if (!instance)
    {
      return;
    }
    bool aHigh = digitalRead(instance->_aPin);
    bool bHigh = digitalRead(instance->_bPin);
    portENTER_CRITICAL_ISR(&instance->_mux);
    if (aHigh == bHigh)
    {
      instance->_count--;
    }
    else
    {
      instance->_count++;
    }
    portEXIT_CRITICAL_ISR(&instance->_mux);
  }

  static SoftHalfQuadEncoder *instance;
  int _aPin = -1;
  int _bPin = -1;
  volatile int64_t _count = 0;
  portMUX_TYPE _mux = portMUX_INITIALIZER_UNLOCKED;
};

SoftHalfQuadEncoder *SoftHalfQuadEncoder::instance = nullptr;

#endif

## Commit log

2025-04-19 V1 Commits
    - Better UI
    - More Robust JSON Parsing
    - Better Button Debounce Implementation
2025-12-30 Configured Interrupts
2026-03-19 Added PCB Design
    [spotifyPlayerPcb.csv, spotifyPlayerPcb.kicad_pcb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]
2026-03-21 Removed Blind Vias
    [spotifyPlayerPcb-B_Cu.gbr, spotifyPlayerPcb-B_Mask.gbr, spotifyPlayerPcb-B_Paste.gbr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]
2026-03-23 Changed OLED Footprint
    [spotifyPlayerPcb-B_Cu.gbr, spotifyPlayerPcb-B_Mask.gbr, spotifyPlayerPcb-B_Paste.gbr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]
2026-07-16 updated PCB + platformio config
    [spotifyPlayerPcb.kicad_sch]
2026-08-28 updated PCB
